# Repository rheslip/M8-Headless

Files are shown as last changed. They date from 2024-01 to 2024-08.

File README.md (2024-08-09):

# M8 Headless
 M8 Headless recipe using Raspberry Pi Zero 2 W
 Jan 2024
 
 short demo https://youtu.be/lyha2_3JbOE 
 
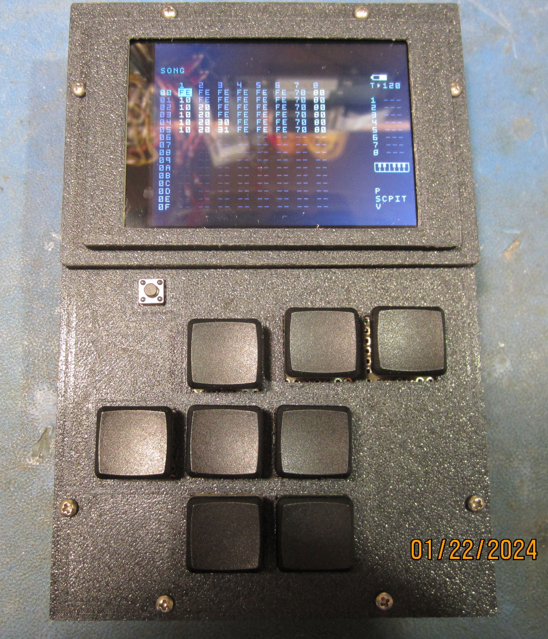
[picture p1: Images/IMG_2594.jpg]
 
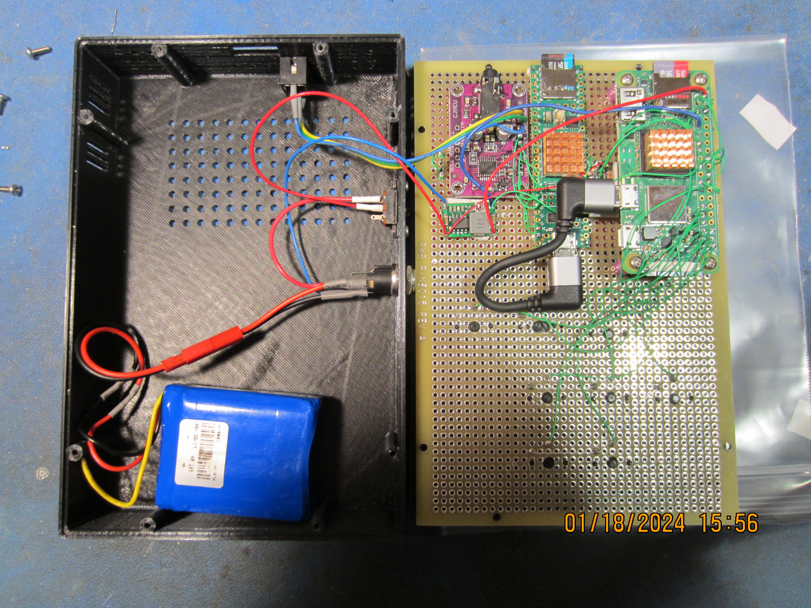
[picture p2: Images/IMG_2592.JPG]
 
 
 UPDATE Aug 9 2024 - M8 headless firmware 4.0 is out with some cool new features but the audio no longer works with a direct connection to the DAC as documented below. I probably should have kept my mouth shut...
 
 Why?

I wanted to try the Dirtywave M8 tracker without spending $$$ on the real deal. I have seen other similar projects using Raspberry Pi 4 but I figured it could be done with a Raspberry Pi Zero 2 W. This build is smaller, cheaper, consumes less power and if I do say so myself is more elegant than the other standalone M8 Headless projects I've seen.
 
 Its relatively cheap to build ~ $150 but it requires serious electronic building skills and experience configuring Linux. 
 
 Why Not? 
 
The headless M8 firmware does not support audio input, MIDI, or touchscreen. If you want the full functions of an M8, buy an M8. If you don't like fiddling with electronics and Linux for days on end, buy an M8.
 
 I have spent at least 60 hours on the project and its still not really finished. Most of that time was researching and configuring Linux to boot into M8C, installing the TFT driver, configuring the GPIOs etc. The actual electronics build was fairly straightforward. The 3D printed enclosure is still in progress but usable.

 Hardware
 
 You will need:
 
 Teensy 4.1 with the M8 headless code installed
 
 Raspberry Pi Zero 2W
 
 Short USB OTG cable to connect the two: I used this one https://www.amazon.ca/dp/B07FBZ963D?psc=1&ref=ppx_yo2ov_dt_b_product_details
 
 8 key switches with caps - I used the same Kailh 1350 low profile switches that are used on the M8. You can find these on Amazon or Aliexpress
 
 Display - one with an ILI9341 controller chip will make things easier. I used this one https://www.amazon.ca/gp/product/B0B1M9S9V6?tag=elfster04-20&th=1
 
 Battery pack and charger. I used a 2S Lipoly 1500mah pack which gives around 4 hrs usage. I used this charger module https://www.aliexpress.com/item/1005006042283437.html?spm=a2g0o.order_list.order_list_main.40.38ee18029ofbrc
 
 5V Step down regulator - I used a cheap one from Aliexpress. You could use a 1S Lipoly with a 5V stepup regulator instead.
 
 Audio DAC - UDA1334 module https://www.adafruit.com/product/3678. I used a cheap knockoff from Aliexpress
 
 SD cards for the Teensy and Pi - see the M8 site for recommended cards for the Teensy
 
 I wired mine on a Vector #8015 protoboard which is 4" x 6". Slightly larger than the M8 but I'm also using a 3.2" display vs the M8's 2.8"
 
 Misc other stuff - wire, on/off switch, tact switch for shutting down the Pi
 
 Power Consumption
 
 I measure about 320ma for the whole shebang (Pi and Teensy) at 7.6V when idle. This jumps up to around 400ma when the screen gets very busy as when a song is playing.

 Wiring
 
There is no wiring diagram. If you can't figure it out from the code and config files then you don't have the skills to complete this project. 

Wire the display to the PI's SPI port, the keyswitches to the GPIO pins specified in /boot/config.txt. I made a drilling template to mount the Kailh switches on the .1" grid protoboard - the leads more or less fit on .1" grid but the plastic mounting pins do not.

There is a tact switch from Pi physical pin 5 to GND as a shutdown switch. This is enabled in /boot/config.txt.

You can wire the DAC directly to the Teensy's I2S pins for audio. Other M8 headless projects seem to loop USB audio from the Teensy to the PI to a DAC attached to the Pi which is not very elegant and chews needless CPU cycles. The UDA1334 module works with its default settings - connect Teensy LRCLK (pin 20), BLCK (pin 21) and OUT1A (pin 7) to the module. The headphone out is very loud so you will probably have to turn down the master level in the M8 mixer screen.

The battery is wired to a 2.1mm power jack so it can be charged with an external charger. I plan to embed the USB C charging module (linked above) in the enclosure at some point.

I wired up a battery gauge using two MIC803-30, a MIC803-31 (what I had) and a resistor divider chain. These pull PI gpio pins 17,27 and 22 low in sequence as the battery voltage drops. I modded the TFT driver low battery code to draw four different battery icons based on the GPIO inputs. The modded code is here as an example of tweeking the TFT driver but its pretty specific to the circuit I used.

Enclosure

There is 3D printable enclosure in OpenSCAD for this project. Its still a work in progress. Its a bit taller, wider and thicker than the M8. The enclosure needs lots of ventilation - heatsinks were added to the Teensy and the Pi. The Pi overheat icon appears on the display sometimes when there is a lot of screen activity and CPU use.

TFT driver

This is the magic that allows 25-45 fps on a PI Zero 2W. It copies the 640x480 X frame buffer to the TFT over the PI's SPI bus. https://github.com/juj/fbcp-ili9341.git 

Very helpful wiring diagrams and installation instructions: https://bytesnbits.co.uk/retropie-raspberry-pi-0-spi-lcd/

You will want to configure your Pi display for 640x480 so it downscales nicely to 320x240 on the TFT. If the TFT display looks fuzzy check LXDE altialiasing may be turned on - see the O/S configuration notes below.

GPIO Keys

I used GPIO keys to generate keypress events which are read by the M8C display software - see /boot/config.txt. It uses the default keycodes for M8C to keep things simple. The other M8 headless implementations I've seen use a Python app running in the background to scan the keys and send keycodes. Why not use the device tree overlay intended for that purpose ?

Linux

There is no prebuilt image for the PI - building it from scratch is educational. This took days of research and testing to get a recipe that works!

Started with Raspberry Pi Bullseye Desktop (32 bit) but the response to the keys was very laggy at times. Switched to DietPi (another couple days work) and the lag issue was greatly reduced. There are still short delays now and then from a keypress until you see the response on the display - Linux swapping, a background task kicking in? Possible performance improvements: R/O filesystem, log to ramdisk etc

My notes on how to build the image - NOT a shell script, its just my way of making notes:

download the Raspberry Pi 32 bit Bullseye (ARMv7) image from https://dietpi.com/downloads/images/

image with Raspberry Pi imager - enable SSH so you can remote login. you could also do the config with a keyboard and screen attached to the Pi

login via SSH: root dietpi (default user/password for this image. don't need sudo because you are root)

when you login via ssh, it runs an update script and then runs the config tool dietpi-launcher. Make these changes:

	disable UART login
	
	set screen rez 640x480
	
	install LXDE desktop. I also changed the ssh server to OpenSSH which works well with WinSCP for remote file management
	
	you have to "exit with install" - it finishes the final installation which takes a while
	
- changes to /boot/config.txt:
 
set to vga mode by uncommenting hdmi_group=1 and hdmi_mode=1
 
uncomment the hdmi_force-hotplug line so it always starts the display code

uncomment the two hdmi_resolution lines

comment the #dtoverlay=vc4-kms-v3d line if present
 
comment the audio, SPI, I2C etc if enabled - the display driver uses its own SPI implementation

add the gpio-key mappings for the keys:
 
	dtoverlay=gpio-key,gpio=5,active_low=1,gpio_pull=up,label=down,keycode=108
	dtoverlay=gpio-key,gpio=6,active_low=1,gpio_pull=up,label=up,keycode=103
	dtoverlay=gpio-key,gpio=13,active_low=1,gpio_pull=up,label=left,keycode=105
	dtoverlay=gpio-key,gpio=19,active_low=1,gpio_pull=up,label=right,keycode=106
	dtoverlay=gpio-key,gpio=26,active_low=1,gpio_pull=up,label=shift,keycode=42
	dtoverlay=gpio-key,gpio=16,active_low=1,gpio_pull=up,label=enter,keycode=31
	dtoverlay=gpio-key,gpio=20,active_low=1,gpio_pull=up,label=option,keycode=30
	dtoverlay=gpio-key,gpio=21,active_low=1,gpio_pull=up,label=play,keycode=57
	dtoverlay=gpio-shutdown    # for the shutdown button on default pin 5
	gpio=17=ip,pu    # set gpio 17 (pin 11) as the low battery input
	gpio=27=ip,pu   # half battery level input
	gpio=22=ip,pu # 3/4 battery level

thats it for changes to /boot/config.txt

- install tools we need to build the TFT driver

apt-get install git 

apt-get install cmake

apt install build-essential  # not even a c compiler in this distro!

apt-get install libraspberrypi-dev raspberrypi-kernel-headers # need these to build the driver

cd /root

git clone https://github.com/juj/fbcp-ili9341.git # get the TFT driver source

cd fbcp-ili9341

- at this point make any source changes to the driver code e.g. if you want a low battery display, battery gauge etc you may want to change config.h and lowbattery.c

mkdir build

cd build

- build line below assumes IlI9341 display driver chip and low battery input on GPIO 17. I had to rotate my display as well

cmake -DILI9341=ON -DGPIO_TFT_DATA_CONTROL=24 -DGPIO_TFT_RESET_PIN=25 -DSPI_BUS_CLOCK_DIVISOR=6 -DDISPLAY_ROTATE_180_DEGREES=ON -DSTATISTICS=0 -DLOW_BATTERY_PIN=17 ..

make -j    #this builds the TFT display code. 

- create a systemd file to start up the TFT service - its not a linux driver, it just runs in the background

nano /etc/systemd/system/fbcp.service  # with contents:

	[Unit]
	Description=Start up FBCP driver
	[Service]
	Type=oneshot
	ExecStart=/root/fbcp-ili9341/build/fbcp-ili9341
	[Install]
	WantedBy=multi-user.target

#start the TFT driver service - will start on next boot:

systemctl enable fbcp.service

- build the M8C display software which runs in the LXDE desktop environment

cd /root

apt install -y git gcc pkg-config make libsdl2-dev libserialport-dev  

mkdir code 

cd code

git clone https://github.com/laamaa/m8c.git   #get the M8C display code

cd m8c

make    # build M8C

- create LXDE autostart file to launch M8C /root/.config/dietpi-desktop_setup.desktop/m8c.desktop with this in it:

	[Desktop Entry]
	Type=Application
	Name=M8C
	Exec=/root/code/m8c/m8c

I didn't have to change the Teensy USB serial port, M8C seemed to find it. YMMV

- tweeks needed to get LXDE to run M8C full screen:

nano /root/.config/openbox/lxde-rc.xml  #add the fragment of xml below. it goes near the bottom of the file in the applications section. this removes the decoration (bar above the app window)

	<application name="*">
        <decor>no</decor>	
        </application>
		
- to remove the LXDE menus comment (with a #) the line @lxpanel --profile LXDE  in the file:

/etc/xdg/lxsession/LXDE/autostart

- to remove the mouse cursor in LXDE add the -nocursor option to the x command in

/etc/X11/xinit/xserverrc 

 - to turn off font antialiasing change iXft/Antialias=1 to iXft/Antialias=0 in the file:

/etc/xdg/lxsession/LXDE/desktop.conf

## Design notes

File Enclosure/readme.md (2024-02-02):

OpenSCAD files for M8 Headless - Jan 2024

The main enclosure and the top use YAPPBox which is a parametric enclosure designing script:
https://github.com/mrWheel/YAPP_Box

I used a slightly older version of the script (V19) with some small tweeks that I don't remember now (modified connectors?). My modded Yappbox script is included.

The bottom of the M8 case is actually what Yappbox calls the top. The PCB dimensions and mounting holes are for a 4x6" Vector board #8015. I fudged the space around the PCB so the PCB sits on the enclosure inner edge which is normally where the other half of the enclosure fits.
I may change this so its a normal top/bottom with the PCB clamped between but this will push the dimensions of the enclosure out a bit.

M8box_04 - revised version of bottom case for USB-C charger module and added a lot more ventilation. Hopefully this prevents the overheat indicator on the Pi desktop. Also added larger heatsinks to both processors.

M8box_05 - even more vents and a cutout for an 18x18mm heatsink I added to the Pi Zero 2 W. Pi desktop still shows an overheat icon if there is a lot of screen activity for ~30 minutes. Not much more I can do to cool it passively.

M8batterybox - I swapped out the 1500mah Lipoly pack for 2x 18650 LIon batteries for more capacity. This box is designed to be glued into the bottom of the case to secure the 18650s.

The top is just a flat sheet with mounting holes that sits on top of the PCB with cutouts for the keys and the shutdown button. It sits on top of the PCB and held to the base part wih 2-56 screws threaded into the bosses in the base. Its not great but it looks better than the raw Vector perfboard PCB. Note that you will have to trim any wires etc that poke thru the top side of the PCB so the top will sit flush.

Print the bezel in two parts (m8bezelbase and m8bezeltop) and glue them together. The first bezel design with supports did not work well - supports were virtually impossible to remove after 3D printing. Bezel mounts on top of the top sheet with 2-56 screws into the same bosses in the base.

If you change the display, the location of the keyswitches etc the files will have to be adjusted accordingly.

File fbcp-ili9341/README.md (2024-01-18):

fbcp-ili9341 modded source files

config.h - added the GPIO pins used for battery gauge

low_battery.c - added four new icons for the battery display and positioned so they are in the same spot as the M8 - under the VU meters. Displays battery full, 3/4, half, or low in red based on the GPIO inputs which are active low.

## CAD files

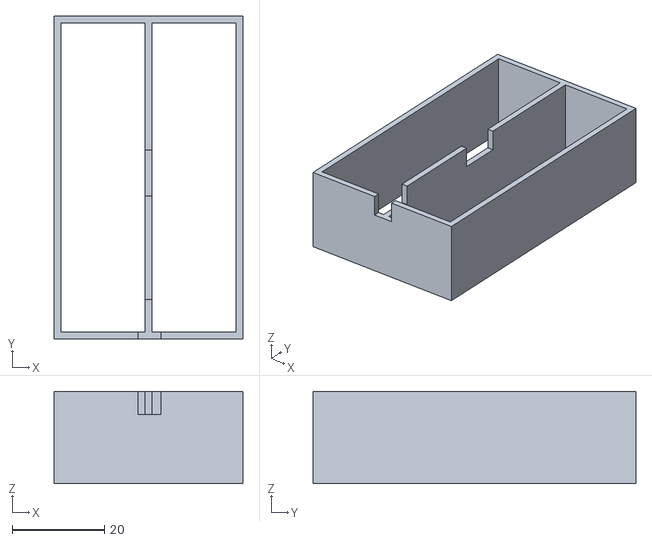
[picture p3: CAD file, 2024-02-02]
Enclosure/M8batterybox.stl
41.0 x 70.0 x 20.0

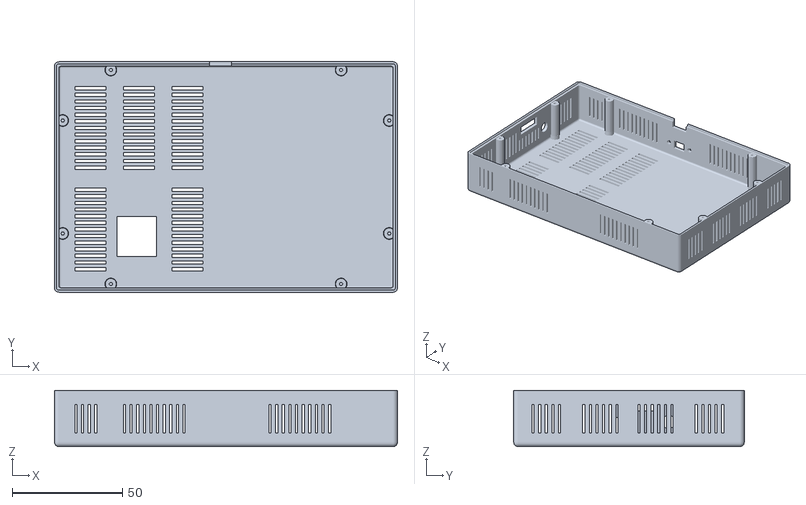
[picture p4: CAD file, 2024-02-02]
Enclosure/m8box_05.stl
155.5 x 104.5 x 25.5

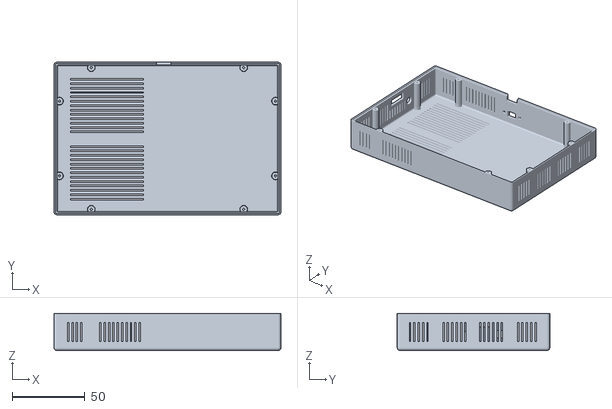
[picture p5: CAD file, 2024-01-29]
Enclosure/m8box_04.stl
155.5 x 104.5 x 25.5

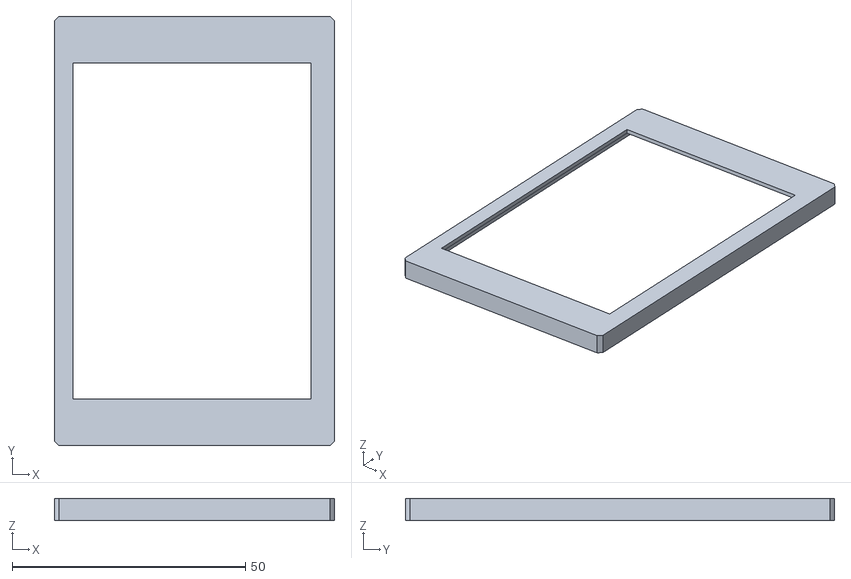
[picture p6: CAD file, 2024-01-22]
Enclosure/m8bezeltop.stl
60.0 x 92.0 x 4.75

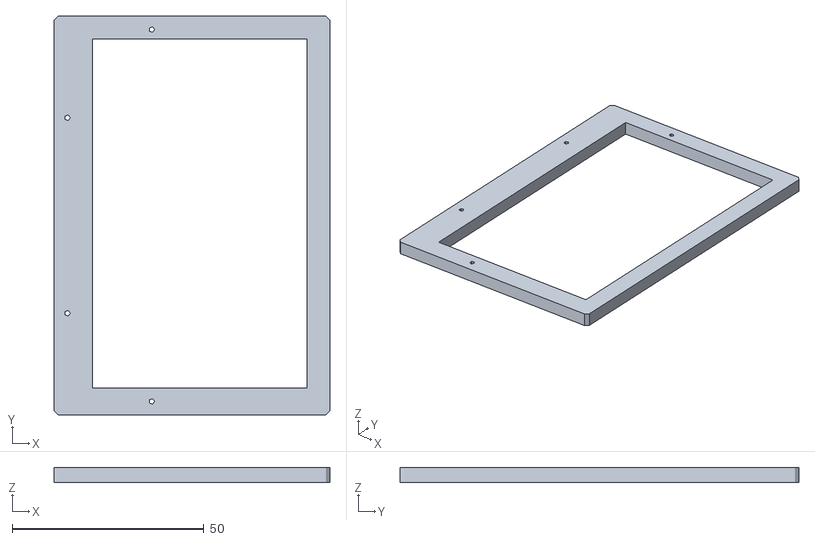
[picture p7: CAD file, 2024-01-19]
Enclosure/m8bezelbase.stl
72.0 x 104.0 x 4.00

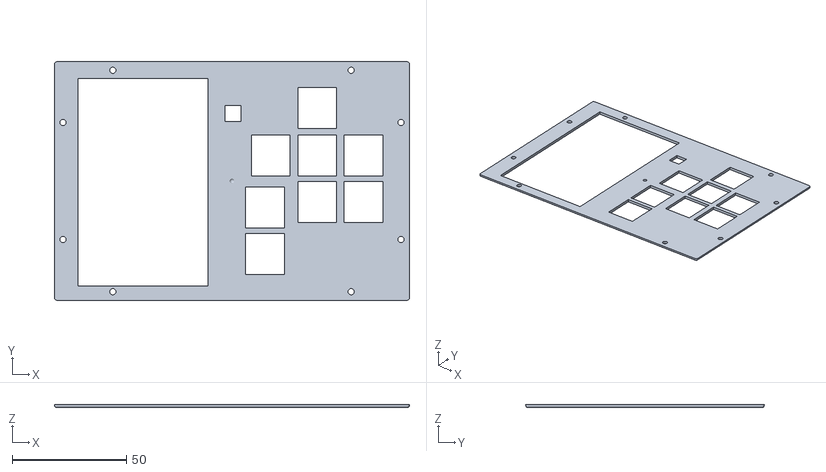
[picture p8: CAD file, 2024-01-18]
Enclosure/m8box_top_03.stl
155.5 x 104.5 x 1.50

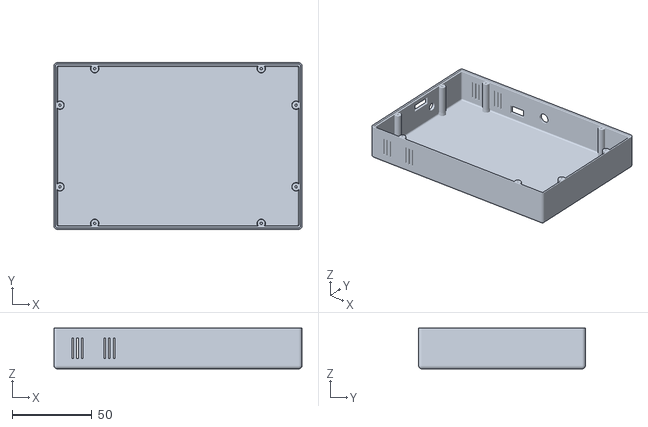
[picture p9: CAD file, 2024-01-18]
Enclosure/m8box_03.stl
155.5 x 104.5 x 25.5

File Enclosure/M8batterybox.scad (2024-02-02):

// M8 battery holder for 2x 18650 Feb 1 2024
// intended to be glued to the bottom inside of the base

width=18.25;  // inside width for one battery
length= 67; // inside length
wall_thickness=1.5;

depth=20;





module rounded_cube(x,y,z,r) {
    linear_extrude(height=z) translate([r,r,0]) offset(r=r) square([x-2*r,y-2*r]);
}

module hollow_cube(width,length,cutx,cuty,cutwidth,cutlength,depth,r) {
    difference () {
        rounded_cube(width,length,depth,r);
        translate([cutx,cuty,-1]) rounded_cube(cutwidth,cutlength,depth+2,0);

    }
}

difference () {
    union() {

        hollow_cube (width+wall_thickness*2,length+wall_thickness*2,wall_thickness      ,wall_thickness,width,length,depth,0);  //
       translate([width+wall_thickness,0,0]) hollow_cube (width+wall_thickness*2,length+wall_thickness*2,wall_thickness      ,wall_thickness,width,length,depth,0);  //  
      
    };
   translate([width,0-wall_thickness,depth-5]) rounded_cube(5,10,6,0); // endcutout for wires
   translate([width,length/2-2.5,depth-5]) rounded_cube(5,10,6,0); // center cutout for wires
}

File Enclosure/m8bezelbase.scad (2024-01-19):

// M8 bezel Jan 18 2024
// split into base and top part that is glued
// supports are impossible to remove when printed in one go

width=104;
wall_thickness=1;
top_thickness=1.0; // top layer over glass
base_height=4;
layer2_height=2;
post_height=10;

module screwhole(hole=3,height=10) {

        cylinder(h=height,r1=hole/2,r2=hole/2,center=true);
}

module rounded_cube(x,y,z,r) {
    linear_extrude(height=z) translate([r,r,0]) offset(r=r) square([x-2*r,y-2*r]);
}

module hollow_cube(height,length,cutx,cuty,cutheight,cutlength,depth,r) {
    difference () {
        rounded_cube(height,length,depth,r);
        translate([cutx,cuty,0]) rounded_cube(cutheight,cutlength,depth,0);

    }
}

difference () {
    union() {
        hollow_cube (72, 104,10,7,56,91,base_height,1); // bottom
   //     translate([8,7,base_height]) hollow_cube (60,89.1+wall_thickness*2,2,5,56,82,layer2_height,1);  // layer over display PCB
   //     translate([8,7,base_height+layer2_height]) hollow_cube (60,89.1+wall_thickness*2,4,10,51,72,top_thickness,1);  // top layer over glass       
    };
    translate([25.5,3.5,0]) screwhole(1.5,post_height); // BL
    translate([25.5,width-3.5,0]) screwhole(1.5,post_height); 
    translate([3.5,26.5,0]) screwhole(1.5,post_height); 
    translate([3.5,width-26.5,0]) screwhole(1.5,post_height); 
}

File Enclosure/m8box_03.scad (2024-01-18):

//---------------------------------------------------------
// This design is parameterized based on the size of a PCB.
//---------------------------------------------------------
include <../YAPP_BOX/library/YAPPgenerator_v19_RH.scad>

// Note: length/lengte refers to X axis, 
//       width/breedte to Y, 
//       height/hoogte to Z

/*
      padding-back|<------pcb length --->|<padding-front
                            RIGHT
        0    X-as ---> 
        +----------------------------------------+   ---
        |                                        |    ^
        |                                        |   padding-right 
        |                                        |    v
        |    -5,y +----------------------+       |   ---              
 B    Y |         | 0,y              x,y |       |     ^              F
 A    - |         |                      |       |     |              R
 C    a |         |                      |       |     | pcb width    O
 K    s |         |                      |       |     |              N
        |         | 0,0              x,0 |       |     v              T
      ^ |   -5,0  +----------------------+       |   ---
      | |                                        |    padding-left
      0 +----------------------------------------+   ---
        0    X-as --->
                          LEFT
*/

//-- which half do you want to print?
printLidShell       = true;
printBaseShell      = false;

//-- Edit these parameters for your own board dimensions
wallThickness       = 2.0;
basePlaneThickness  = 1.5;
lidPlaneThickness   = 1.5;

//-- Total height of box = basePlaneThickness + lidPlaneThickness 
//--                     + baseWallHeight + lidWallHeight
//-- space between pcb and lidPlane :=
//--      (baseWallHeight+lidWallHeight) - (standoffHeight+pcbThickness)
baseWallHeight      = 4;
lidWallHeight       = 23;

//-- ridge where base and lid off box can overlap
//-- Make sure this isn't less than lidWallHeight
ridgeHeight         = 1.5;
ridgeSlack          = 0.2;
roundRadius         = 2.0;


//-- pcb dimensions
pcbLength           = 153;
pcbWidth            = 102;
pcbThickness        = 1.65;

//-- How much the PCB needs to be raised from the base
//-- to leave room for solderings and whatnot
standoffHeight      = 2.5;
pinDiameter         = 2.0;
pinHoleSlack        = 0.5;
standoffDiameter    = 4;
standoffSupportHeight   = 2.0;
standoffSupportDiameter = 0.10;
                            
//-- padding between pcb and inside wall
paddingFront        = -0.75;
paddingBack         = -0.75;
paddingRight        = -0.75;
paddingLeft         = -0.75;


//-- D E B U G ----------------------------
showSideBySide      = true;       //-> true
onLidGap            = 0;
shiftLid            = 1;
hideLidWalls        = false;       //-> false
colorLid            = "yellow";   
hideBaseWalls       = false;       //-> false
colorBase           = "white";
showPCB             = false;      //-> false
showMarkers         = false;      //-> false
inspectX            = 0;  //-> 0=none (>0 from front, <0 from back)
inspectY            = 0;
//-- D E B U G ----------------------------

// pcb connectors - instead of pins we can use screws to secure the PCB
//-- normal         : origen = box[0,0,0]
//-- yappConnWithPCB: origen = pcb[0,0,0]
// (0) = posx
// (1) = posy
// (2) = pcbStandHeight   <--!
// (3) = screwDiameter
// (4) = screwHeadDiameter
// (5) = insertDiameter
// (6) = outsideDiameter
// (7) = flangeHeight
// (8) = flangeDiam
// (9) = { yappConnWithPCB }
// (10) = { yappAllCorners | yappFrontLeft | yappFrondRight | yappBackLeft | yappBackRight }
                
                
connectors   =  [
                    [ 2.5, 25.4, 2.5, 2.75, 5.5, 1.5, 5, 3, 5.5, yappConnWithPCB,yappAllCorners],
                [ 24.3, 2.5, 2.5, 2.75, 5.5, 1.5, 5, 3, 5.5, yappConnWithPCB,yappAllCorners]
                ];
                

//-- pcb_standoffs  -- origin is pcb[0,0,0]
// (0) = posx
// (1) = posy
// (2) = { yappBoth | yappLidOnly | yappBaseOnly }
// (3) = { yappHole, YappPin }
pcbStands = [
           //     [3,3,yappBoth,yappPin],
            //    [pcbLength-3,3,yappBoth,yappPin],
            //    [pcbLength-3,pcbWidth-3,yappBoth,yappPin],
           //     [3,pcbWidth-3,yappBoth,yappPin]
             ];


//-- Lid plane    -- origin is pcb[0,0,0]
// (0) = posx
// (1) = posy
// (2) = width
// (3) = length
// (4) = angle
// (5) = { yappRectangle | yappCircle }
// (6) = { yappCenter }
cutoutsLid =  [ 
            //        [10, 10, 10, 15, 30, yappRectangle]
            //      , [10, 10, 5, 0, 0, yappCircle]
            //      , [pcbLength/2, pcbWidth/2, 10, 15, 45, yappRectangle, yappCenter]
            //      , [pcbLength/2, pcbWidth/2, 5, 0, 0, yappCircle]
              ];

//-- base plane    -- origin is pcb[0,0,0]
// (0) = posx
// (1) = posy
// (2) = width
// (3) = length
// (4) = angle
// (5) = { yappRectangle | yappCircle }
// (6) = { yappCenter }
cutoutsBase = [
            //        [10, 10, 10, 15, 30, yappRectangle]
            //      , [10, 10, 5, 0, 0, yappCircle]
           //       , [pcbLength/2, pcbWidth/2, 10, 15, 45, yappRectangle, yappCenter]
          //        , [pcbLength/2, pcbWidth/2, 5, 0, 0, yappCircle]
              ];

//-- front plane  -- origin is pcb[0,0,0]
// (0) = posy
// (1) = posz
// (2) = width
// (3) = height
// (4) = angle
// (5) = { yappRectangle | yappCircle }
// (6) = { yappCenter }
cutoutsFront =  [
          //           [10, 10, 12, 15, 10, yappRectangle]
          //         , [10, 10, 5, 0, 0, yappCircle]
         //          , [40, 10, 10, 8, 0, yappRectangle, yappCenter]
         //          , [40, 10, 5, 0, 0, yappCircle]
                ];

//-- back plane  -- origin is pcb[0,0,0]
// (0) = posy
// (1) = posz
// (2) = width
// (3) = height
// (4) = angle
// (5) = { yappRectangle | yappCircle }
// (6) = { yappCenter }
cutoutsBack = [
                     [40.0, 3, 15, 5, 0, yappRectangle] // sd card
                   , [35, 13, 6, 0, 0, yappCircle] // headphone jack
         //          , [40, 10, 10, 8, 0, yappRectangle, yappCenter]
         //          , [40, 10, 5, 0, 0, yappCircle]
              ];

//-- left plane   -- origin is pcb[0,0,0]
// (0) = posx
// (1) = posz
// (2) = width
// (3) = height
// (4) = angle
// (5) = { yappRectangle | yappCircle }
// (6) = { yappCenter }
cutoutsLeft = [
                  [45, 12, 11.5, 6.0, 0, yappRectangle] // switch slot
                 , [75, 12, 7.5, 0, 0, yappCircle] // charging jack
                 ,[10, 5, 1.0, 13.0, 0, yappRectangle] // vent
                 ,[13, 5, 1.0, 13.0, 0, yappRectangle] // vent
                 ,[16, 5, 1.0, 13.0, 0, yappRectangle] // vent
                 ,[30, 5, 1.0, 13.0, 0, yappRectangle] // vent
                 ,[33, 5, 1.0, 13.0, 0, yappRectangle] // vent
                 ,[36, 5, 1.0, 13.0, 0, yappRectangle] // vent
      //            [10, 10, 12, 15, 10, yappRectangle]
       //         , [10, 10, 5, 0, 0, yappCircle]
      //          , [50, 10, 10, 8, 20, yappRectangle, yappCenter]
      //          , [50, 10, 5, 0, 0, yappCircle]
              ];

//-- right plane   -- origin is pcb[0,0,0]
// (0) = posx
// (1) = posz
// (2) = width
// (3) = height
// (4) = angle
// (5) = { yappRectangle | yappCircle }
// (6) = { yappCenter }
cutoutsRight = [
                 [10, 5, 1.0, 13.0, 0, yappRectangle] // vent
                 ,[13, 5, 1.0, 13.0, 0, yappRectangle] // vent
                 ,[16, 5, 1.0, 13.0, 0, yappRectangle] // vent
                 ,[30, 5, 1.0, 13.0, 0, yappRectangle] // vent
                 ,[33, 5, 1.0, 13.0, 0, yappRectangle] // vent
                 ,[36, 5, 1.0, 13.0, 0, yappRectangle] // vent

      //          , [50, 10, 10, 8, 20, yappRectangle, yappCenter]
     //           , [50, 10, 5, 0, 0, yappCircle]
               ];




//-- base mounts -- origen = box[x0,y0]
// (0) = posx | posy
// (1) = screwDiameter
// (2) = width
// (3) = height
// (4..7) = yappLeft / yappRight / yappFront / yappBack (one or more)
// (5) = { yappCenter }
baseMounts   = [
                //     [60, 3.3, 20, 3, yappBack, yappLeft]
                //   , [50, 3.3, 30, 3, yappRight, yappFront, yappCenter]
                //   , [20, 3, 5, 3, yappRight]
                //   , [10, 3, 5, 3, yappBack]
                //   , [4, 3, 34, 3, yappFront]
                //   , [25, 3, 3, 3, yappBack]
                //   , [5, 3.2, shellWidth-10, 3, yappFront]
               ];

               
//-- snapJons -- origen = shell[x0,y0]
// (0) = posx | posy
// (1) = width
// (2..5) = yappLeft / yappRight / yappFront / yappBack (one or more)
// (n) = { yappSymmetric }
snapJoins   =   [
              //      [15,  5, yappLeft, yappRight, yappSymmetric]
             //     , [5,  5, yappFront, yappBack, yappSymmetric]
                ];
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

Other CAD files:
Enclosure/m8bezeltop.scad
Enclosure/YAPPgenerator_v19_RH.scad
Enclosure/m8box_04.scad
Enclosure/m8box_05.scad
Enclosure/m8box_top_03.scad

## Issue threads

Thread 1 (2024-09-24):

DAC helping

DRCRecoveryData, 2024-09-24:
Hi,
From schematic i got:

## Teensy 4.1 Connections to SGTL5000 Audio Board

| Teensy 4.1 Pin | SGTL5000 Audio Board Pin | Function          |
|----------------|--------------------------|-------------------|
| 7              | I2S DIN (7)              | Data Input        |
| 8              | I2S DOUT (8)             | Data Output       |
| 18             | SDA (18)                 | I2C Data          |
| 19             | SCL (19)                 | I2C Clock         |
| 20             | LRCLK (20)               | Left-Right Clock  |
| 21             | BCLK (21)                | Bit Clock         |

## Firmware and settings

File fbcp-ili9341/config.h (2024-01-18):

#pragma once

// Build options: Uncomment any of these, or set at the command line to configure:

// If defined, renders a performance overlay on top of the screen. This option is passed from CMake
// configuration script. If you are getting statistics printed on screen
// even when this is uncommented, pass -DSTATISTICS=0 to CMake invocation line. You can also try
// building with
//   'make VERBOSE=1'
// to see which config flags are coming from CMake to the build.
// #define STATISTICS

// How often the on-screen statistics is refreshed (in usecs)
#define STATISTICS_REFRESH_INTERVAL 200000
// How many usecs worth of past frame rate data do we preserve in the history buffer. Higher values
// make the frame rate display counter smoother and respond to changes with a delay, whereas smaller
// values can make the display fluctuate a bit erratically.
#define FRAMERATE_HISTORY_LENGTH 400000

// If enabled, displays a visual graph of frame completion times
// #define FRAME_COMPLETION_TIME_STATISTICS

// If defined, no sleeps are specified and the code runs as fast as possible. This should not improve
// performance, as the code has been developed with the mindset that sleeping should only occur at
// times when there is no work to do, rather than sleeping to reduce power usage. The only expected
// effect of this is that CPU usage shoots to 200%, while display update FPS is the same. Present
// here to allow toggling to debug this assumption.
// #define NO_THROTTLING

// If defined, display updates are synced to the vsync signal provided by the VideoCore GPU. That seems
// to occur quite precisely at 60 Hz. Testing on PAL NES games that run at 50Hz, this will not work well,
// since they produce new frames at every 20msecs, and the VideoCore functions for snapshotting also will
// output new frames at this vsync-detached interval, so there's a 50 Hz vs 60 Hz mismatch that results
// in visible microstuttering. Still, providing this as an option, this might be good for content that
// is known to run at native 60Hz.
// #define USE_GPU_VSYNC

// Always enable GPU VSync on the Pi Zero. Even though it is suboptimal and can cause stuttering, it saves battery.
#if defined(SINGLE_CORE_BOARD)

#if !defined(USE_GPU_VSYNC)
#define USE_GPU_VSYNC
#endif

#else // Multicore Pi boards (Pi 2, 3)

// If defined, communication with the SPI bus is handled with a dedicated thread. On the Pi Zero, this does
// not gain much, since it only has one hardware thread.
#define USE_SPI_THREAD

// If USE_GPU_VSYNC is defined, then enabling this causes new frames to be snapshot more often than at
// TARGET_FRAME_RATE interval to try to keep up smoother 60fps instead of stuttering. Consumes more CPU.
#define SELF_SYNCHRONIZE_TO_GPU_VSYNC_PRODUCED_NEW_FRAMES

#endif

// If enabled, the source video frame is not scaled to fit to the screen, but instead if the source frame
// is bigger than the SPI display, then content is cropped away, i.e. the source is displayed "centered"
// on the SPI screen:
// #define DISPLAY_CROPPED_INSTEAD_OF_SCALING

// If enabled, the main thread and SPI thread are executed with realtime priority
// #define RUN_WITH_REALTIME_THREAD_PRIORITY

// If defined, progressive updating is always used (at the expense of slowing down refresh rate if it's
// too much for the display to handle)
// #define NO_INTERLACING

#if (defined(FREEPLAYTECH_WAVESHARE32B) || (defined(ILI9341) && SPI_BUS_CLOCK_DIVISOR <= 4)) && defined(USE_DMA_TRANSFERS) && !defined(NO_INTERLACING)
// The Freeplaytech CM3/Zero displays actually only have a visible display resolution of 302x202, instead of
// 320x240, and this is enough to give them full progressive 320x240x60fps without ever resorting to
// interlacing. Also, ILI9341 displays running with clock divisor of 4 have enough bandwidth to never need
// interlacing either.
#define NO_INTERLACING
#endif

// If defined, all frames are always rendered as interlaced, and never use progressive rendering.
// #define ALWAYS_INTERLACING

// By default, if the SPI bus is idle after rendering an interlaced frame, but the GPU has not yet produced
// a new application frame to be displayed, the same frame will be rendered again for its other field.
// Define this option to disable this behavior, in which case when an interlaced frame is rendered, the 
// remaining other field half of the image will never be uploaded.
// #define THROTTLE_INTERLACING

// The ILI9486 has to resort to interlacing as a rule rather than exception, and it works much smoother
// when applying throttling to interlacing, so enable it by default there.
#if defined(ILI9486) || defined(HX8357D)
#define THROTTLE_INTERLACING
#endif

// If defined, DMA usage is foremost used to save power consumption and CPU usage. If not defined,
// DMA usage is tailored towards maximum performance.
// #define ALL_TASKS_SHOULD_DMA
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

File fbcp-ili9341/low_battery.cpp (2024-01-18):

#include <string.h>

#include "config.h"
#include "low_battery.h"
#include "gpu.h"
#include "spi.h"

#ifdef LOW_BATTERY_PIN
// this is confusing because X and Y are swapped from convention
#define LOW_BATTERY_ICON_TOP_LEFT_X 42
#define LOW_BATTERY_ICON_TOP_LEFT_Y 273
#define LOW_BATTERY_ICON_WIDTH 11
#define LOW_BATTERY_ICON_HEIGHT 20
#define FULL_BATTERY_FORE_COLOR 65535 // white
//#define LOW_BATTERY_FORE_COLOR 0x00ff  // blue
#define LOW_BATTERY_FORE_COLOR 0xf000  // Red
#define LOW_BATTERY_BACK_COLOR 0

static bool lowBattery = false;
static bool threeqBattery = false;
static bool halfBattery = false;
static uint64_t lowBatteryLastPolled = 0;

/*
// Battery icon from: https://github.com/martinohanlon/grrl-bat-monitor
static uint16_t lowBatteryIcon [LOW_BATTERY_ICON_HEIGHT][LOW_BATTERY_ICON_WIDTH] = {
        {0, 0, 0, 0, 0, 0, 0, 0, 0, 0, 0, 0, 0, 0, 0, 0, 0, 0, 0, 0, 0, 0, 0, 0, 0, 0, 0, 0, 0, 0, 0, 0, 0, 0, 0},
        {0, 0, 0, 0, 0, 0, 0, 0, 0, 0, 0, 0, 0, 0, 0, 0, 0, 0, 0, 0, 0, 0, 0, 0, 0, 0, 0, 0, 0, 0, 0, 0, 0, 0, 0},
        {0, 0, 1, 1, 1, 1, 1, 1, 1, 1, 1, 1, 1, 1, 1, 1, 1, 1, 1, 1, 1, 1, 1, 1, 1, 1, 1, 1, 1, 0, 0, 0, 0, 0, 0},
        {0, 0, 1, 1, 1, 1, 1, 1, 1, 1, 1, 1, 1, 1, 1, 1, 1, 1, 1, 1, 1, 1, 1, 1, 1, 1, 1, 1, 1, 0, 0, 0, 0, 0, 0},
        {0, 0, 1, 1, 0, 0, 0, 0, 0, 0, 0, 0, 0, 0, 0, 0, 0, 0, 0, 0, 0, 0, 0, 0, 0, 0, 0, 1, 1, 1, 1, 0, 0, 0, 0},
        {0, 0, 1, 1, 0, 0, 0, 0, 0, 0, 0, 0, 0, 0, 0, 0, 0, 0, 0, 0, 0, 0, 0, 0, 0, 0, 0, 1, 1, 1, 1, 0, 0, 0, 0},
        {0, 0, 1, 1, 0, 0, 1, 1, 1, 0, 0, 0, 0, 0, 0, 0, 0, 0, 0, 0, 0, 0, 0, 0, 0, 0, 0, 1, 1, 1, 1, 0, 0, 0, 0},
        {0, 0, 1, 1, 0, 0, 1, 1, 1, 0, 0, 0, 0, 0, 0, 0, 0, 0, 0, 0, 0, 0, 0, 0, 0, 0, 0, 1, 1, 1, 1, 0, 0, 0, 0},
        {0, 0, 1, 1, 0, 0, 1, 1, 1, 0, 0, 0, 0, 0, 0, 0, 0, 0, 0, 0, 0, 0, 0, 0, 0, 0, 0, 0, 0, 1, 1, 1, 1, 0, 0},
        {0, 0, 1, 1, 0, 0, 1, 1, 1, 0, 0, 0, 0, 0, 0, 0, 0, 0, 0, 0, 0, 0, 0, 0, 0, 0, 0, 0, 0, 1, 1, 1, 1, 0, 0},
        {0, 0, 1, 1, 0, 0, 1, 1, 1, 0, 0, 0, 0, 0, 0, 0, 0, 0, 0, 0, 0, 0, 0, 0, 0, 0, 0, 0, 0, 1, 1, 1, 1, 0, 0},
        {0, 0, 1, 1, 0, 0, 1, 1, 1, 0, 0, 0, 0, 0, 0, 0, 0, 0, 0, 0, 0, 0, 0, 0, 0, 0, 0, 0, 0, 1, 1, 1, 1, 0, 0},
        {0, 0, 1, 1, 0, 0, 1, 1, 1, 0, 0, 0, 0, 0, 0, 0, 0, 0, 0, 0, 0, 0, 0, 0, 0, 0, 0, 1, 1, 1, 1, 0, 0, 0, 0},
        {0, 0, 1, 1, 0, 0, 1, 1, 1, 0, 0, 0, 0, 0, 0, 0, 0, 0, 0, 0, 0, 0, 0, 0, 0, 0, 0, 1, 1, 1, 1, 0, 0, 0, 0},
        {0, 0, 1, 1, 0, 0, 0, 0, 0, 0, 0, 0, 0, 0, 0, 0, 0, 0, 0, 0, 0, 0, 0, 0, 0, 0, 0, 1, 1, 1, 1, 0, 0, 0, 0},
        {0, 0, 1, 1, 0, 0, 0, 0, 0, 0, 0, 0, 0, 0, 0, 0, 0, 0, 0, 0, 0, 0, 0, 0, 0, 0, 0, 1, 1, 1, 1, 0, 0, 0, 0},
        {0, 0, 1, 1, 1, 1, 1, 1, 1, 1, 1, 1, 1, 1, 1, 1, 1, 1, 1, 1, 1, 1, 1, 1, 1, 1, 1, 1, 1, 0, 0, 0, 0, 0, 0},
        {0, 0, 1, 1, 1, 1, 1, 1, 1, 1, 1, 1, 1, 1, 1, 1, 1, 1, 1, 1, 1, 1, 1, 1, 1, 1, 1, 1, 1, 0, 0, 0, 0, 0, 0},
        {0, 0, 0, 0, 0, 0, 0, 0, 0, 0, 0, 0, 0, 0, 0, 0, 0, 0, 0, 0, 0, 0, 0, 0, 0, 0, 0, 0, 0, 0, 0, 0, 0, 0, 0},
        {0, 0, 0, 0, 0, 0, 0, 0, 0, 0, 0, 0, 0, 0, 0, 0, 0, 0, 0, 0, 0, 0, 0, 0, 0, 0, 0, 0, 0, 0, 0, 0, 0, 0, 0}};
*/
/* building block lines for new icons
        {0, 0, 0, 0, 0, 0, 0},
		{0, 0, 1, 1, 1, 0, 0},
		{1, 1, 1, 1, 1, 1, 1},
        {1, 0, 0, 0, 0, 0, 1},
		{1, 0, 1, 1, 1, 0, 1},
		{1, 1, 1, 1, 1, 1, 1},
*/

static uint16_t lowBatteryIcon [LOW_BATTERY_ICON_HEIGHT][LOW_BATTERY_ICON_WIDTH] = {
		{0, 0, 1, 1, 1, 0, 0},
		{0, 0, 1, 1, 1, 0, 0},
		{1, 1, 1, 1, 1, 1, 1},
		{1, 0, 0, 0, 0, 0, 1},
		{1, 0, 0, 0, 0, 0, 1},
		{1, 0, 0, 0, 0, 0, 1},
		{1, 0, 0, 0, 0, 0, 1},
		{1, 0, 0, 0, 0, 0, 1},
		{1, 0, 0, 0, 0, 0, 1},
		{1, 0, 0, 0, 0, 0, 1},
		{1, 0, 0, 0, 0, 0, 1},
		{1, 0, 0, 0, 0, 0, 1},
		{1, 0, 0, 0, 0, 0, 1},
		{1, 0, 0, 0, 0, 0, 1},
		{1, 0, 0, 0, 0, 0, 1},
		{1, 0, 0, 0, 0, 0, 1},
		{1, 1, 1, 1, 1, 1, 1},
		{1, 1, 1, 1, 1, 1, 1},
		{1, 1, 1, 1, 1, 1, 1},
		{1, 1, 1, 1, 1, 1, 1},
	
		};

static uint16_t fullBatteryIcon [LOW_BATTERY_ICON_HEIGHT][LOW_BATTERY_ICON_WIDTH] = {
		{0, 0, 1, 1, 1, 0, 0},
		{0, 0, 1, 1, 1, 0, 0},
		{1, 1, 1, 1, 1, 1, 1},
		{1, 1, 1, 1, 1, 1, 1},
		{1, 1, 1, 1, 1, 1, 1},
		{1, 1, 1, 1, 1, 1, 1},
		{1, 1, 1, 1, 1, 1, 1},
		{1, 1, 1, 1, 1, 1, 1},
		{1, 1, 1, 1, 1, 1, 1},
		{1, 1, 1, 1, 1, 1, 1},
		{1, 1, 1, 1, 1, 1, 1},
		{1, 1, 1, 1, 1, 1, 1},
		{1, 1, 1, 1, 1, 1, 1},
		{1, 1, 1, 1, 1, 1, 1},
		{1, 1, 1, 1, 1, 1, 1},
		{1, 1, 1, 1, 1, 1, 1},
		{1, 1, 1, 1, 1, 1, 1},
		{1, 1, 1, 1, 1, 1, 1},
		{1, 1, 1, 1, 1, 1, 1},
		{1, 1, 1, 1, 1, 1, 1},	
		};

static uint16_t threeqBatteryIcon [LOW_BATTERY_ICON_HEIGHT][LOW_BATTERY_ICON_WIDTH] = {
		{0, 0, 1, 1, 1, 0, 0},
		{0, 0, 1, 1, 1, 0, 0},
		{1, 1, 1, 1, 1, 1, 1},
		{1, 0, 0, 0, 0, 0, 1},
		{1, 0, 0, 0, 0, 0, 1},
		{1, 0, 0, 0, 0, 0, 1},
		{1, 0, 0, 0, 0, 0, 1},
		{1, 1, 1, 1, 1, 1, 1},
		{1, 1, 1, 1, 1, 1, 1},
		{1, 1, 1, 1, 1, 1, 1},
		{1, 1, 1, 1, 1, 1, 1},
		{1, 1, 1, 1, 1, 1, 1},
		{1, 1, 1, 1, 1, 1, 1},
		{1, 1, 1, 1, 1, 1, 1},
		{1, 1, 1, 1, 1, 1, 1},
		{1, 1, 1, 1, 1, 1, 1},
		{1, 1, 1, 1, 1, 1, 1},
		{1, 1, 1, 1, 1, 1, 1},
		{1, 1, 1, 1, 1, 1, 1},
		{1, 1, 1, 1, 1, 1, 1},	
		};

static uint16_t halfBatteryIcon [LOW_BATTERY_ICON_HEIGHT][LOW_BATTERY_ICON_WIDTH] = {
		{0, 0, 1, 1, 1, 0, 0},
		{0, 0, 1, 1, 1, 0, 0},
		{1, 1, 1, 1, 1, 1, 1},
		{1, 0, 0, 0, 0, 0, 1},
		{1, 0, 0, 0, 0, 0, 1},
		{1, 0, 0, 0, 0, 0, 1},
		{1, 0, 0, 0, 0, 0, 1},	
		{1, 0, 0, 0, 0, 0, 1},
		{1, 0, 0, 0, 0, 0, 1},
		{1, 0, 0, 0, 0, 0, 1},
		{1, 0, 0, 0, 0, 0, 1},
		{1, 1, 1, 1, 1, 1, 1},
		{1, 1, 1, 1, 1, 1, 1},
		{1, 1, 1, 1, 1, 1, 1},
		{1, 1, 1, 1, 1, 1, 1},
		{1, 1, 1, 1, 1, 1, 1},
		{1, 1, 1, 1, 1, 1, 1},
		{1, 1, 1, 1, 1, 1, 1},
		{1, 1, 1, 1, 1, 1, 1},
		{1, 1, 1, 1, 1, 1, 1},	
		};
		
void InitLowBatterySystem()
{
  for(int y = 0; y < LOW_BATTERY_ICON_HEIGHT; ++y)
    for(int x = 0; x < LOW_BATTERY_ICON_WIDTH; ++x)
      lowBatteryIcon[y][x] = lowBatteryIcon[y][x] ? LOW_BATTERY_FORE_COLOR : LOW_BATTERY_BACK_COLOR;
  for(int y = 0; y < LOW_BATTERY_ICON_HEIGHT; ++y)  // RH added new icons
    for(int x = 0; x < LOW_BATTERY_ICON_WIDTH; ++x)
      fullBatteryIcon[y][x] = fullBatteryIcon[y][x] ? FULL_BATTERY_FORE_COLOR : LOW_BATTERY_BACK_COLOR;
  for(int y = 0; y < LOW_BATTERY_ICON_HEIGHT; ++y)  // 
    for(int x = 0; x < LOW_BATTERY_ICON_WIDTH; ++x)
      threeqBatteryIcon[y][x] = threeqBatteryIcon[y][x] ? FULL_BATTERY_FORE_COLOR : LOW_BATTERY_BACK_COLOR;
  for(int y = 0; y < LOW_BATTERY_ICON_HEIGHT; ++y)  // 
    for(int x = 0; x < LOW_BATTERY_ICON_WIDTH; ++x)
      halfBatteryIcon[y][x] = halfBatteryIcon[y][x] ? FULL_BATTERY_FORE_COLOR : LOW_BATTERY_BACK_COLOR;	  
  PollLowBattery();
}
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

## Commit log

2024-01-18 added source files and images
    [config.txt, m8box_03.scad, m8box_03.stl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]
2024-01-19 Added enclosure bezel files, updated readmes
    [YAPPgenerator_v19_RH.scad, m8bezelbase.scad, m8bezelbase.stl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]
2024-01-22 Updated Bezel SCAD files, added video link
    [m8bezeltop.scad, m8bezeltop.stl]
2024-01-29 Revised enclosure base for more ventilation and USB-C charger
    [m8box_04.scad, m8box_04.stl]
2024-02-02 Added latest enclosure files
    [M8batterybox.scad, M8batterybox.stl, m8box_05.scad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]
